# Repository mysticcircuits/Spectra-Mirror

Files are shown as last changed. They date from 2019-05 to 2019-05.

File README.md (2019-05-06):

# Spectra-Mirror

The Spectra Mirror is an analog downsampler with a bunch of bells and whistles not found in other downsamplers.
The module is currently discontinued but is now available in an open hardware licence for those who still want
to build one.  Most of the well known DIY synth retailers as of now still have a few boards in stock, so if you
would like to build one without going through the process of getting the boards made yourself go ahead and
check them out, currently thonk, modular addict and synthcube all have them in stock.

The entire build is through hole with easy to find parts, there is one optional SMD matched transistor pair for 
those wanting superior tracking of the internal VCO.  I would say that this project is not for a complete beginner 
but would be quite easy for anyone with a fair amount of DIY experience.  The calibration procedure requires at 
least a multimeter and benefits from the use of an oscilloscope, although again this is not crucial.  Please read 
the build documentation if you want a better idea of the level of difficulty for the build.

For any questions or comments please visit the MW thread here 
https://www.muffwiggler.com/forum/viewtopic.php?p=2418444#2418444

========= FOR THOSE ATTEMPTING THE MATCHED TRANSISTOR PAIR =========

The following parts will be needed.  I am specifically making you source them as a "barrier for entry" as doing 
this matched transistor pair is not for DIY beginners.  SMD soldering aptitude is required.

Transistor pair is by diodes incorporated part # ZXTC2045E6TA

You will also need a 22k resistor and a 22nF capacitor.

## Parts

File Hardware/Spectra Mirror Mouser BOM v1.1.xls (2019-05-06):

SPECTRA-MIRROR |  |  | WEBLINK TO NON MOUSER PARTS: | Qty. | Notes
 |  | alpha | http://smallbear-electronics.mybigcommerce.com/alpha-single-gang-9mm-right-angle-pc-mount/ | 7 | Order 100kB linear variant
 |  |  | https://modularaddict.com/parts/synth-diy-parts/9mm-potentiometers
 |  |  | https://www.thonk.co.uk/shop/alpha-9mm-pots/
 | R0904N – B 100K , L- 25 KQ | song huei | https://www.thonk.co.uk/shop/ttpots/ | 3 | Order 100kB linear variant
 |  |  | https://modularaddict.com/parts/synth-diy-parts/9mm-tall-trimmer-potentiometers
 | PJ301BM | Kobiconn | https://www.thonk.co.uk/shop/3-5mm-jacks/ | 12 | be sure to buy washers
 |  |  | https://modularaddict.com/parts/jacks/pj301bm-jacks |  | only available in bag of 50 from here
 |  |  | http://smallbear-electronics.mybigcommerce.com/knurled-silver-center-colors/ | 7 | these are the knobs I use, in violet color
 |  |  | http://smallbear-electronics.mybigcommerce.com/large-fluted-silver-center-dot-index-colors/ | 1 | same as above
Mouser # | Mfr. # | Manufacturer | Description – MOUSER PARTS: | Order Qty.
595-TL074CNE4 | TL074CNE4 | Texas Instruments | Operational Amplifiers - Op Amps Quad Low-Noise JFET-Input | 2
926-LF398N/NOPB | LF398N/NOPB | Texas Instruments | Sample & Hold Amplifiers MONOLITHIC SAMPLE & HOLD CIRCUIT | 1
926-LM13700N/NOPB | LM13700N/NOPB | Texas Instruments | Transconductance Amplifiers Dual OP Amp Transconductance | 1
810-FK28C0G1H220J | FK28C0G1H220J | TDK | Multilayer Ceramic Capacitors MLCC - Leaded 22pF 50V C0G 5% | 1
80-R82EC2100AA50J | R82EC2100AA50J | Kemet | Film Capacitors 100volts 0.01uF 5% | 2
71-CCF5010K0FKE36 | CCF5010K0FKE36 | Vishay | Metal Film Resistors - Through Hole 1/3watts 10Kohms 1% | 4
71-CCF0747K0JKE36 | CCF0747K0JKE36 | Vishay | Metal Film Resistors - Through Hole 1/4watt 47Kohms 5% Rated to 1/2watt | 1
71-CCF07220KGKE36 | CCF07220KGKE36 | Vishay | Metal Film Resistors - Through Hole 1/4watt 220Kohms 2% Rated to 1/2watt | 15
71-CCF50-100K | CCF50100KFKR36 | Vishay | Metal Film Resistors - Through Hole 1/3watts 100Kohms 1% | 17
71-CCF501K00FKE36 | CCF501K00FKE36 | Vishay | Metal Film Resistors - Through Hole 1/3watts 1Kohms 1% | 10
71-CCF0722K0GKE36 | CCF0722K0GKE36 | Vishay | Metal Film Resistors - Through Hole 1/4watt 22Kohms 2% Rated to 1/2watt | 4
571-1-2199298-2 | 1-2199298-2 | TE Connectivity | IC & Component Sockets 8P DIP SKT 300 CL LADDER | 6
571-1-2199298-3 | 1-2199298-3 | TE Connectivity | IC & Component Sockets 14P DIP SKT 300 CL LADDER | 2
571-1-2199298-4 | 1-2199298-4 | TE Connectivity | IC & Component Sockets 16P DIP SKT 300 CL LADDER | 1
623-2743002112LF | 2743002112 | Fair-Rite | Ferrite Beads 43 BEAD ON LEAD Z=133OHM @ 100MHz | 2
625-1N4001E-E3/73 | 1N4001E-E3/73 | Vishay | Rectifiers Vr/50V Io/1A | 2
140-REA100M1HBK0511P | REA100M1HBK-0511P | Lelon | Aluminum Electrolytic Capacitors - Leaded 50V 10uF 20% 5x11mm | 2
517-929974-01-13-RK | 929974-01-13-RK | 3M | Headers & Wire Housings 13 CON STR BRDMNT SKT | 2
660-MFS1/4LCT52R153J | MFS1/4LCT52R153J | KOA Speer | Metal Film Resistors - Through Hole 15K ohm 5% | 1
71-RN60D-F-5K | RN60D5001FB14 | Vishay | Metal Film Resistors - Through Hole 1/4watt 5Kohms 1% 100ppm | 1
652-3296W-1-104LF | 3296W-1-104LF | Bourns | Trimmer Resistors - Through Hole 3/8" 100Kohms Sealed Vertical Adjust | 1
652-3296W-1-503LF | 3296W-1-503LF | Bourns | Trimmer Resistors - Through Hole 3/8" 50Kohms Sealed Vertical Adjust | 1
652-3296W-1-102LF | 3296W-1-102LF | Bourns | Trimmer Resistors - Through Hole 3/8" 1Kohms Sealed Vertical Adjust | 1
595-TL071CP | TL071CP | Texas Instruments | Operational Amplifiers - Op Amps JFET Input Low Noise | 1
595-TL072IP | TL072IP | Texas Instruments | Operational Amplifiers - Op Amps Dual JFET In Low N | 3
696-SLX-LX3054ID | SLX-LX3054ID | Lumex | Standard LEDs - Through Hole 3mm LED Lamps | 2
512-2N3906TFR | 2N3906TFR | Fairchild Semiconductor | Bipolar Transistors - BJT PNP Transistor General Purpose | 1
512-2N3904BU | 2N3904BU | Fairchild Semiconductor | Bipolar Transistors - BJT NPN Transistor General Purpose | 1
603-MFR-25FRF521M | MFR-25FRF52-1M | Yageo | Metal Film Resistors - Through Hole 1M ohm 1/4W 1% | 1
647-QYX1H222KTP | QYX1H222KTP | Nichicon | Film Capacitors 50volts 0.0022uF | 1
855-M22-2020505 | M22-2020505 | Harwin | Headers & Wire Housings 5+5 DIL PIN HDR GOLD VERTICAL | 1
571-4-146262-1 | 4-146262-1 | TE Connectivity | Headers & Wire Housings 06 MODII HDR DRST B/A 100W/HD | 2
81-PV36W504C01B00 | PV36W504C01B00 | Bourns | Trimmer Resistors - Through Hole 500Kohms 10mm Square 25turn | 1
595-LT1013CP | LT1013CP | Texas Instruments | Precision Amplifiers Dual Precision | 1
594-K104K15X7RF5UH5 | K104K15X7RF5UH5 | Vishay | Multilayer Ceramic Capacitors MLCC - Leaded .1uF 50volts 10% 5.0mm X7R | 1

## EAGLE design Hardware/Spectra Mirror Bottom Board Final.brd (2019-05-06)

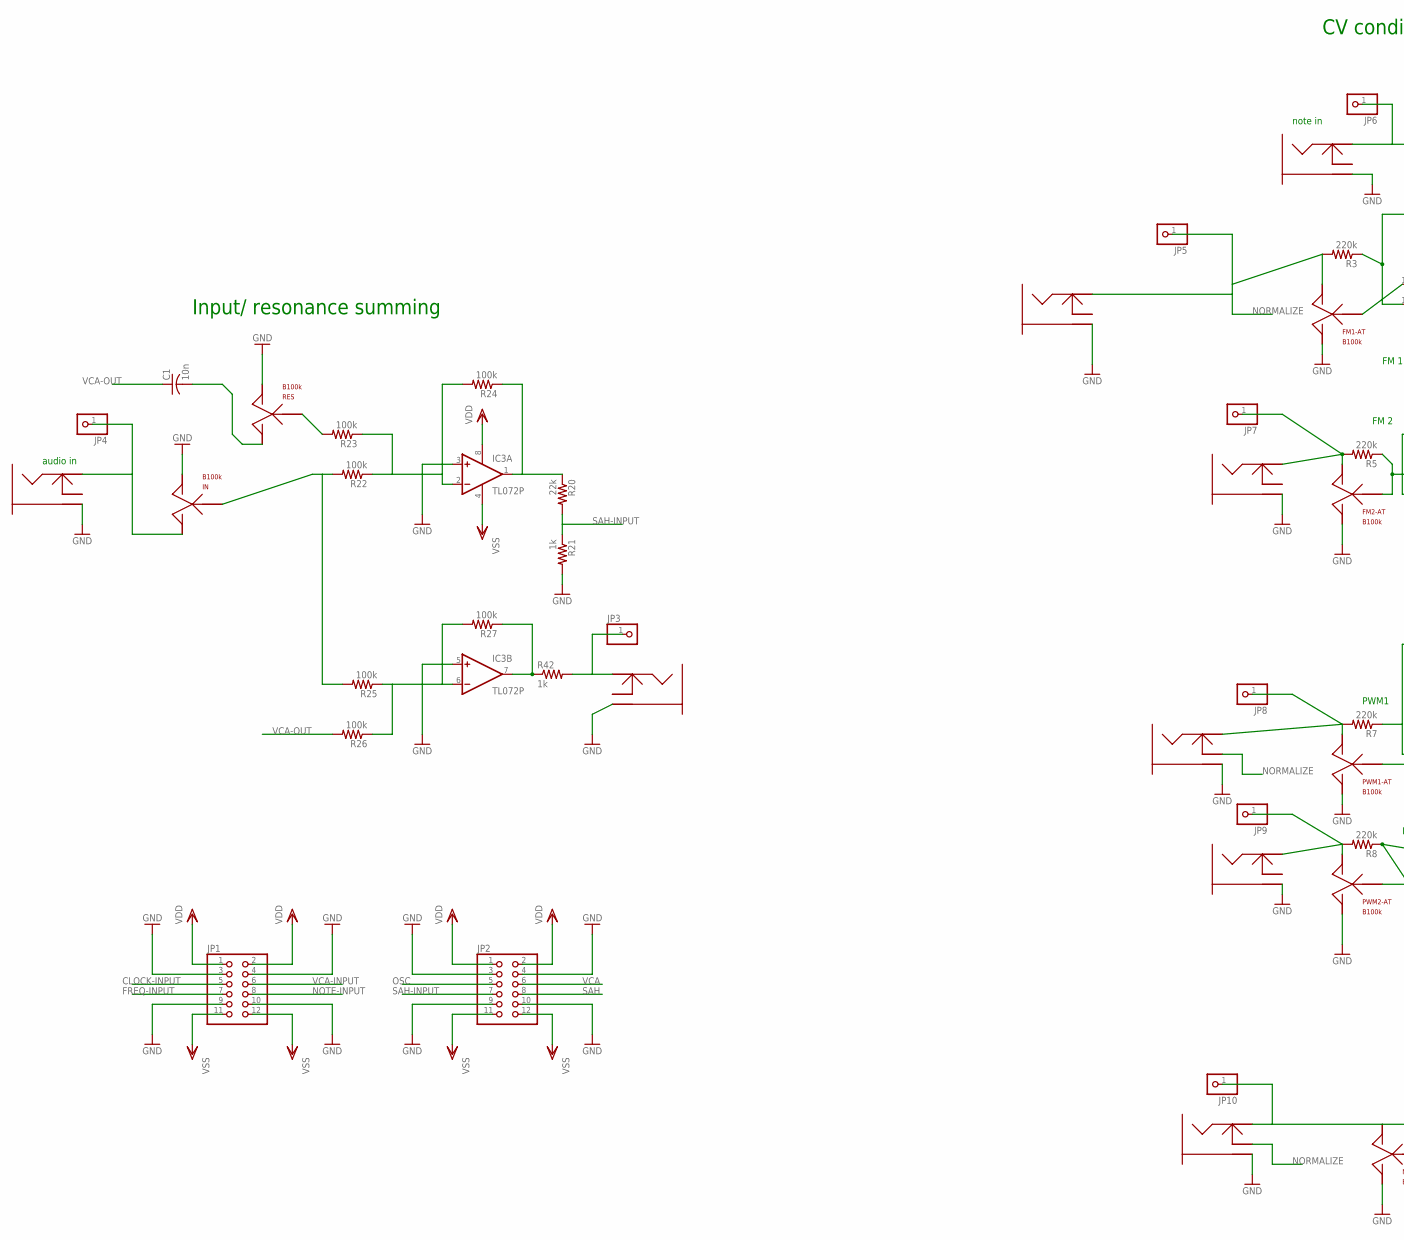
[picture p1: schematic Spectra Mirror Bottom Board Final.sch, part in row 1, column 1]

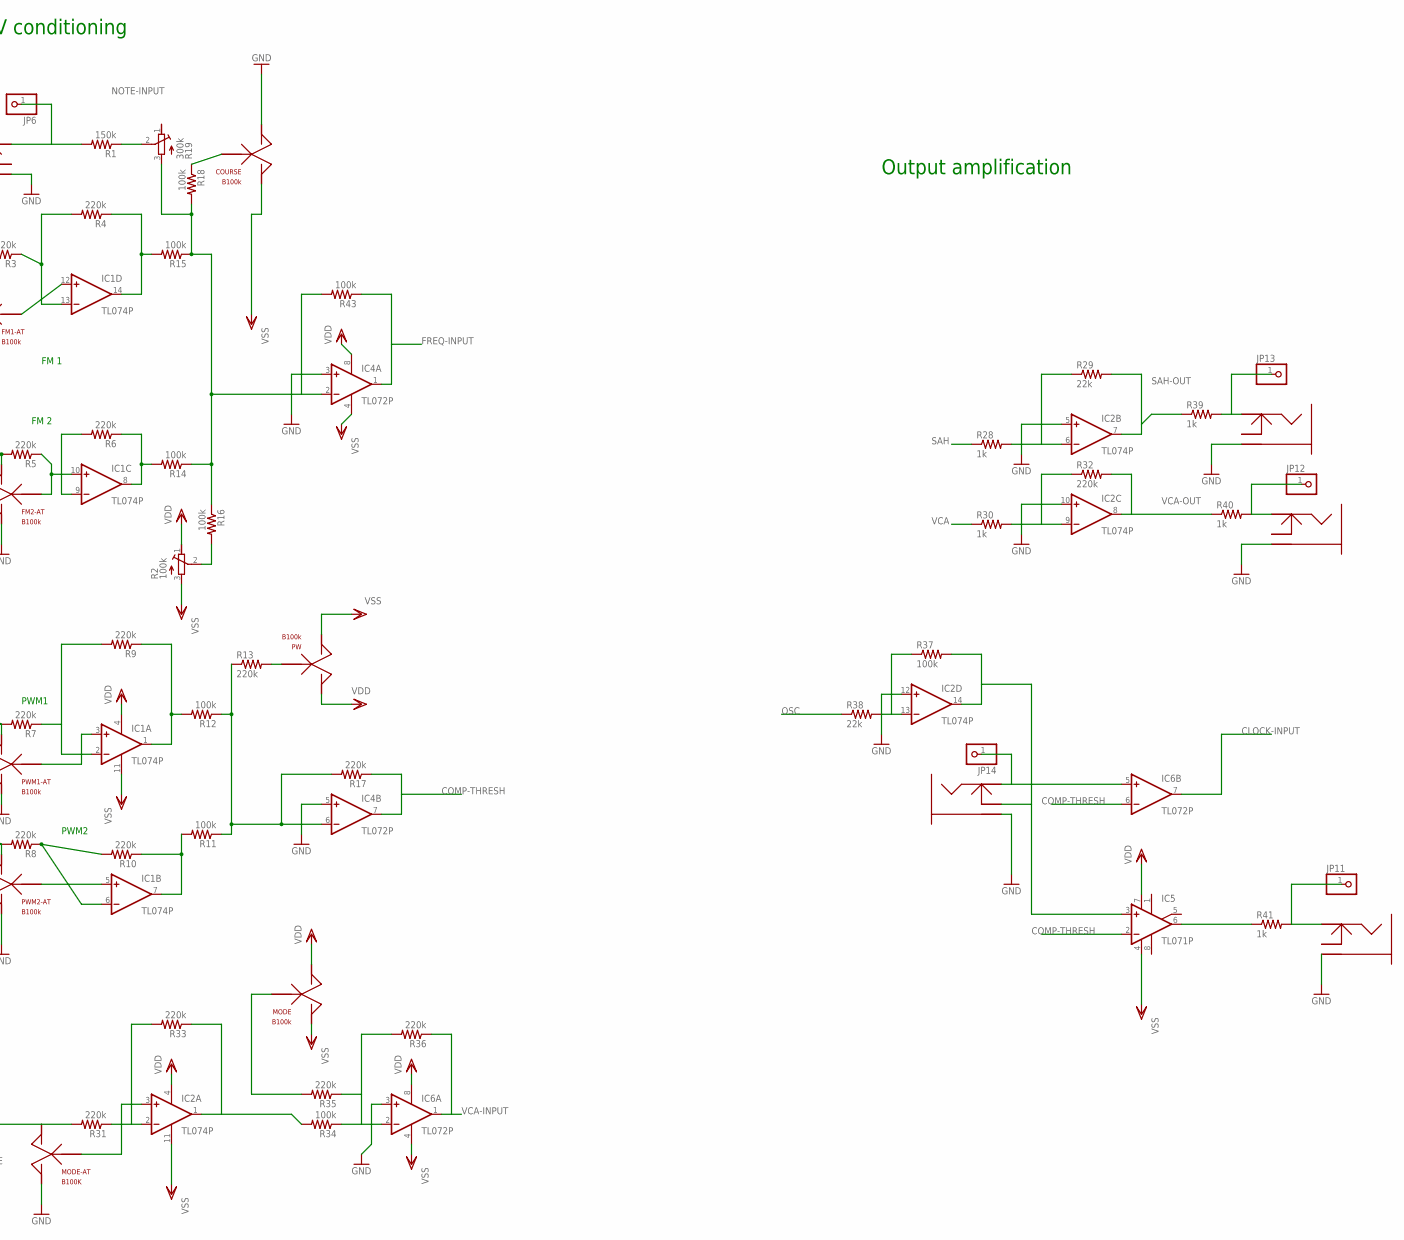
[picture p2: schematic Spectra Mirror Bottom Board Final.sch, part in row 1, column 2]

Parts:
C1: 10n; C050-025X075
COURSE: B100k; ALPHAPOT_BOARDMOUNT
FM1-AT, FM2-AT: B100k; ALPHAPOT_BOARDMOUNT
IC1, IC2: TL074P; DIL14
IC3, IC4, IC6: TL072P; DIL08
IC5: TL071P; DIL08
IN: B100k; ALPHAPOT_BOARDMOUNT
JP1, JP2: PINHD-2X6; 2X06
JP3, JP4, JP5, JP6, JP7, JP8, JP9, JP10, JP11, JP12, JP13, JP14: PINHD-1X1; 1X01
MODE: B100k; ALPHAPOT_BOARDMOUNT
MODE-AT: B100K; ALPHAPOT_BOARDMOUNT
PW: B100k; ALPHAPOT_BOARDMOUNT
PWM1-AT, PWM2-AT: B100k; ALPHAPOT_BOARDMOUNT
R1: 150k; 0204/7
R2: 100k; RTRIMT93YA
R3, R5, R7, R8, R10, R13, R17, R31, R32, R35, R36: 220k; 0204/7
R4, R6, R9, R33: 220k; 0204V
R11, R12, R14, R15, R16, R18, R22, R23, R24, R25, R26, R27, R34, R43: 100k; 0204/7
R19: 300k; RTRIMT93YA
R20, R38: 22k; 0204/7
R21, R28, R30, R39, R40, R41, R42: 1k; 0204/7
R29: 22k; 0204V
R37: 100k; 0204V
RES: B100k; ALPHAPOT_BOARDMOUNT
U$1, U$2, U$3, U$4, U$5, U$6, U$7, U$8, U$9, U$10, U$11, U$12: KOBICONPJ-301

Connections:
CLOCK-INPUT: IC6.7 (OUT), JP1.5
COMP-THRESH: IC4.7 (OUT), IC5.2 (-IN), IC6.6 (-IN), R17.1
FREQ-INPUT: IC4.1 (OUT), JP1.7, R43.1
GND: COURSE.LEFT, FM1-AT.RIGHT, FM2-AT.RIGHT, IC2.5 (+IN), IC2.10 (+IN), IC2.12 (+IN), IC3.3 (+IN), IC3.5 (+IN), IC4.3 (+IN), IC4.5 (+IN), IC6.3 (+IN), IN.RIGHT, JP1.3, JP1.4, JP1.9, JP1.10, JP2.3, JP2.4, JP2.9, JP2.10, MODE-AT.RIGHT, PWM1-AT.RIGHT, PWM2-AT.RIGHT, R21.2, RES.RIGHT, U$1.GND (GROUND), U$1.GND2 (GROUND), U$2.GND (GROUND), U$2.GND2 (GROUND), U$3.GND (GROUND), U$3.GND2 (GROUND), U$4.GND (GROUND), U$4.GND2 (GROUND), U$5.GND (GROUND), U$5.GND2 (GROUND), U$6.GND (GROUND), U$6.GND2 (GROUND), U$7.GND (GROUND), U$7.GND2 (GROUND), U$8.GND (GROUND), U$8.GND2 (GROUND), U$9.GND (GROUND), U$9.GND2 (GROUND), U$10.GND (GROUND), U$10.GND2 (GROUND), U$11.GND (GROUND), U$11.GND2 (GROUND), U$12.GND (GROUND), U$12.GND2 (GROUND)
KJDNFKDNF: IC1.13 (-IN), R3.1, R4.2
unnamed: R1.1, R19.2 (S)
unnamed: R2.2 (S), R16.2
unnamed: IC5.6 (OUT), R41.1
unnamed: IC1.14 (OUT), R4.1, R15.2
unnamed: FM1-AT.MID, IC1.12 (+IN)
unnamed: FM2-AT.MID, IC1.10 (+IN), R5.1
unnamed: IC1.9 (-IN), R6.2
unnamed: FM2-AT.LEFT, JP7.1, R5.2, U$4.IN (INPUT)
unnamed: IC1.8 (OUT), R6.1, R14.2
unnamed: JP9.1, PWM2-AT.LEFT, R8.2, U$11.IN (INPUT)
unnamed: IC1.6 (-IN), R8.1, R10.2
unnamed: JP8.1, PWM1-AT.LEFT, R7.2, U$12.IN (INPUT)
unnamed: IC1.2 (-IN), R7.1, R9.2
unnamed: IC1.1 (OUT), R9.1, R12.2
unnamed: IC1.3 (+IN), PWM1-AT.MID
unnamed: IC1.5 (+IN), PWM2-AT.MID
unnamed: IC1.7 (OUT), R10.1, R11.2
unnamed: IC4.6 (-IN), R11.1, R12.1, R13.1, R17.2
unnamed: PW.MID, R13.2
unnamed: IC4.2 (-IN), R14.1, R15.1, R16.1, R18.2, R19.3 (A), R43.2
unnamed: COURSE.MID, R18.1
unnamed: JP10.1, MODE-AT.LEFT, R31.2, U$10.IN (INPUT)
unnamed: IN.LEFT, JP4.1, U$1.IN (INPUT)
unnamed: IN.MID, R22.2, R25.2
unnamed: IC3.6 (-IN), R25.1, R26.1, R27.2
unnamed: IC3.1 (OUT), R20.1, R24.1
unnamed: IC2.2 (-IN), R31.1, R33.2
unnamed: IC3.2 (-IN), R22.1, R23.1, R24.2
unnamed: IC3.7 (OUT), R27.1, R42.1
unnamed: R23.2, RES.MID
unnamed: IC2.1 (OUT), R33.1, R34.2
unnamed: IC2.9 (-IN), R30.2, R32.1
unnamed: IC2.3 (+IN), MODE-AT.MID
unnamed: IC2.6 (-IN), R28.2, R29.1
unnamed: C1.2, RES.LEFT
unnamed: IC6.2 (-IN), R34.1, R35.1, R36.2
unnamed: IC2.13 (-IN), R37.1, R38.2
unnamed: IC2.14 (OUT), IC5.3 (+IN), R37.2, U$9.SWITCH
unnamed: MODE.MID, R35.2
unnamed: IC6.5 (+IN), JP14.1, U$9.IN (INPUT)
unnamed: JP11.1, R41.2, U$5.IN (INPUT)
unnamed: JP12.1, R40.2, U$7.IN (INPUT)
unnamed: JP13.1, R39.2, U$6.IN (INPUT)
unnamed: JP3.1, R42.2, U$8.IN (INPUT)
NORMALIZE: FM1-AT.LEFT, JP5.1, R3.2, U$3.IN (INPUT), U$10.SWITCH, U$12.SWITCH
NOTE-INPUT: JP1.8, JP6.1, R1.2, U$2.IN (INPUT)
OSC: JP2.5, R38.1
SAH: JP2.8, R28.1
SAH-INPUT: JP2.7, R20.2, R21.1
SAH-OUT: IC2.7 (OUT), R29.2, R39.1
VCA: JP2.6, R30.1
VCA-INPUT: IC6.1 (OUT), JP1.6, R36.1
VCA-OUT: C1.1, IC2.8 (OUT), R26.2, R32.2, R40.1
VDD: IC1.4 (V+), IC2.4 (V+), IC3.8 (V+), IC4.8 (V+), IC5.7 (V+), IC6.8 (V+), JP1.1, JP1.2, JP2.1, JP2.2, MODE.LEFT, PW.LEFT, R2.1 (E)
VSS: COURSE.RIGHT, IC1.11 (V-), IC2.11 (V-), IC3.4 (V-), IC4.4 (V-), IC5.4 (V-), IC6.4 (V-), JP1.11, JP1.12, JP2.11, JP2.12, MODE.RIGHT, PW.RIGHT, R2.3 (A)

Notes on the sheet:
note in
FM 1
FM 2
audio in
PWM1
PWM2
Input/ resonance summing
CV conditioning
Output amplification

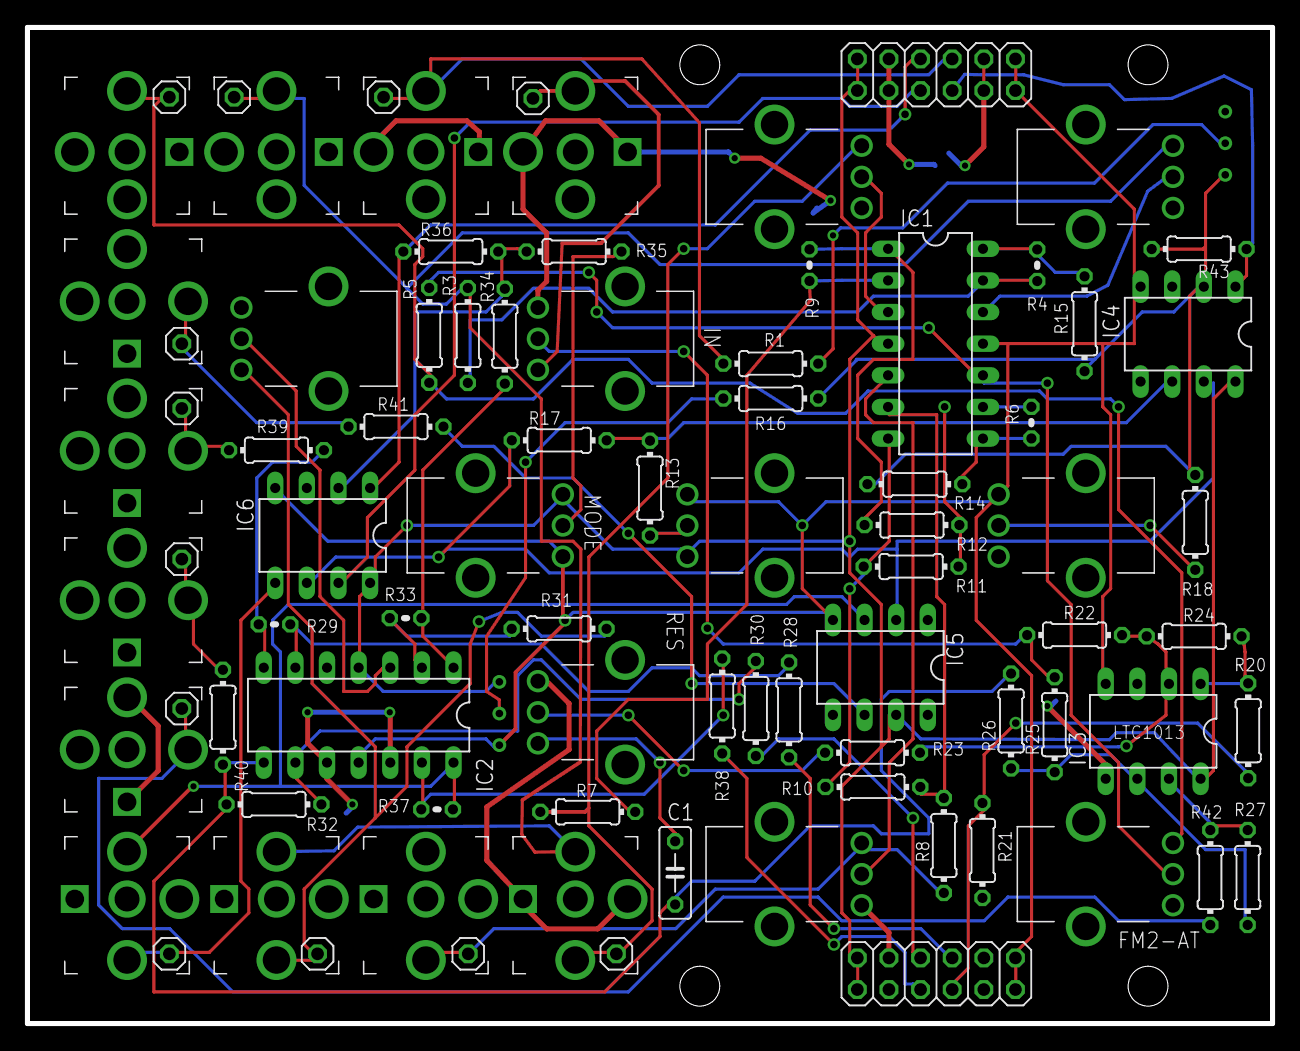
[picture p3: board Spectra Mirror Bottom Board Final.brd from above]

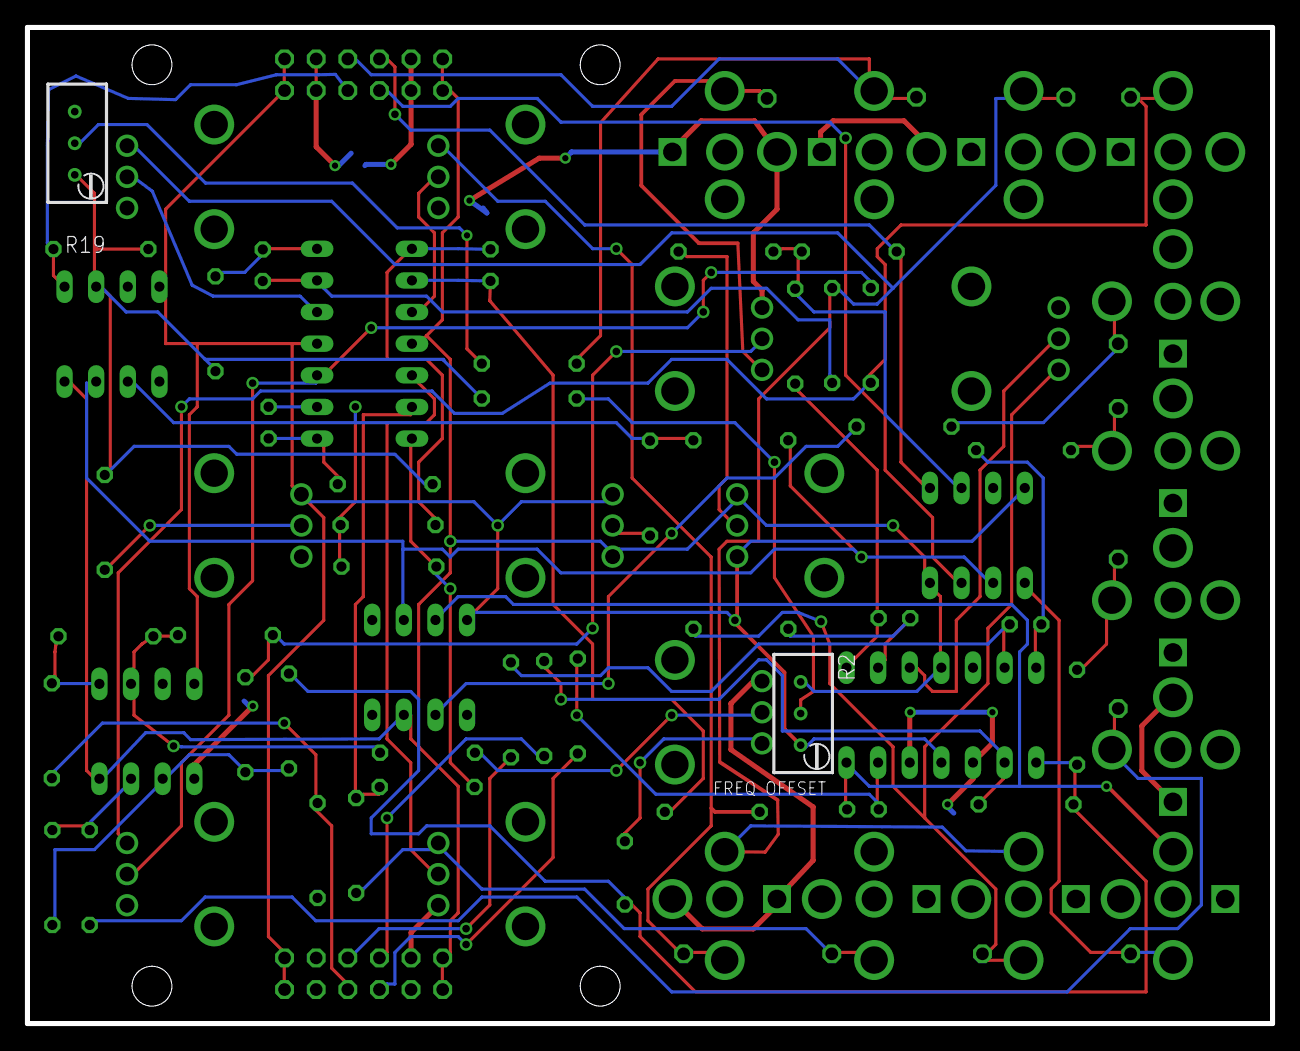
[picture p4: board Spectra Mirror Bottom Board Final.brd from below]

Board: 2 copper layers, 100.0 x 80.0 mm, 86 parts (2 on the bottom side), 60 nets.

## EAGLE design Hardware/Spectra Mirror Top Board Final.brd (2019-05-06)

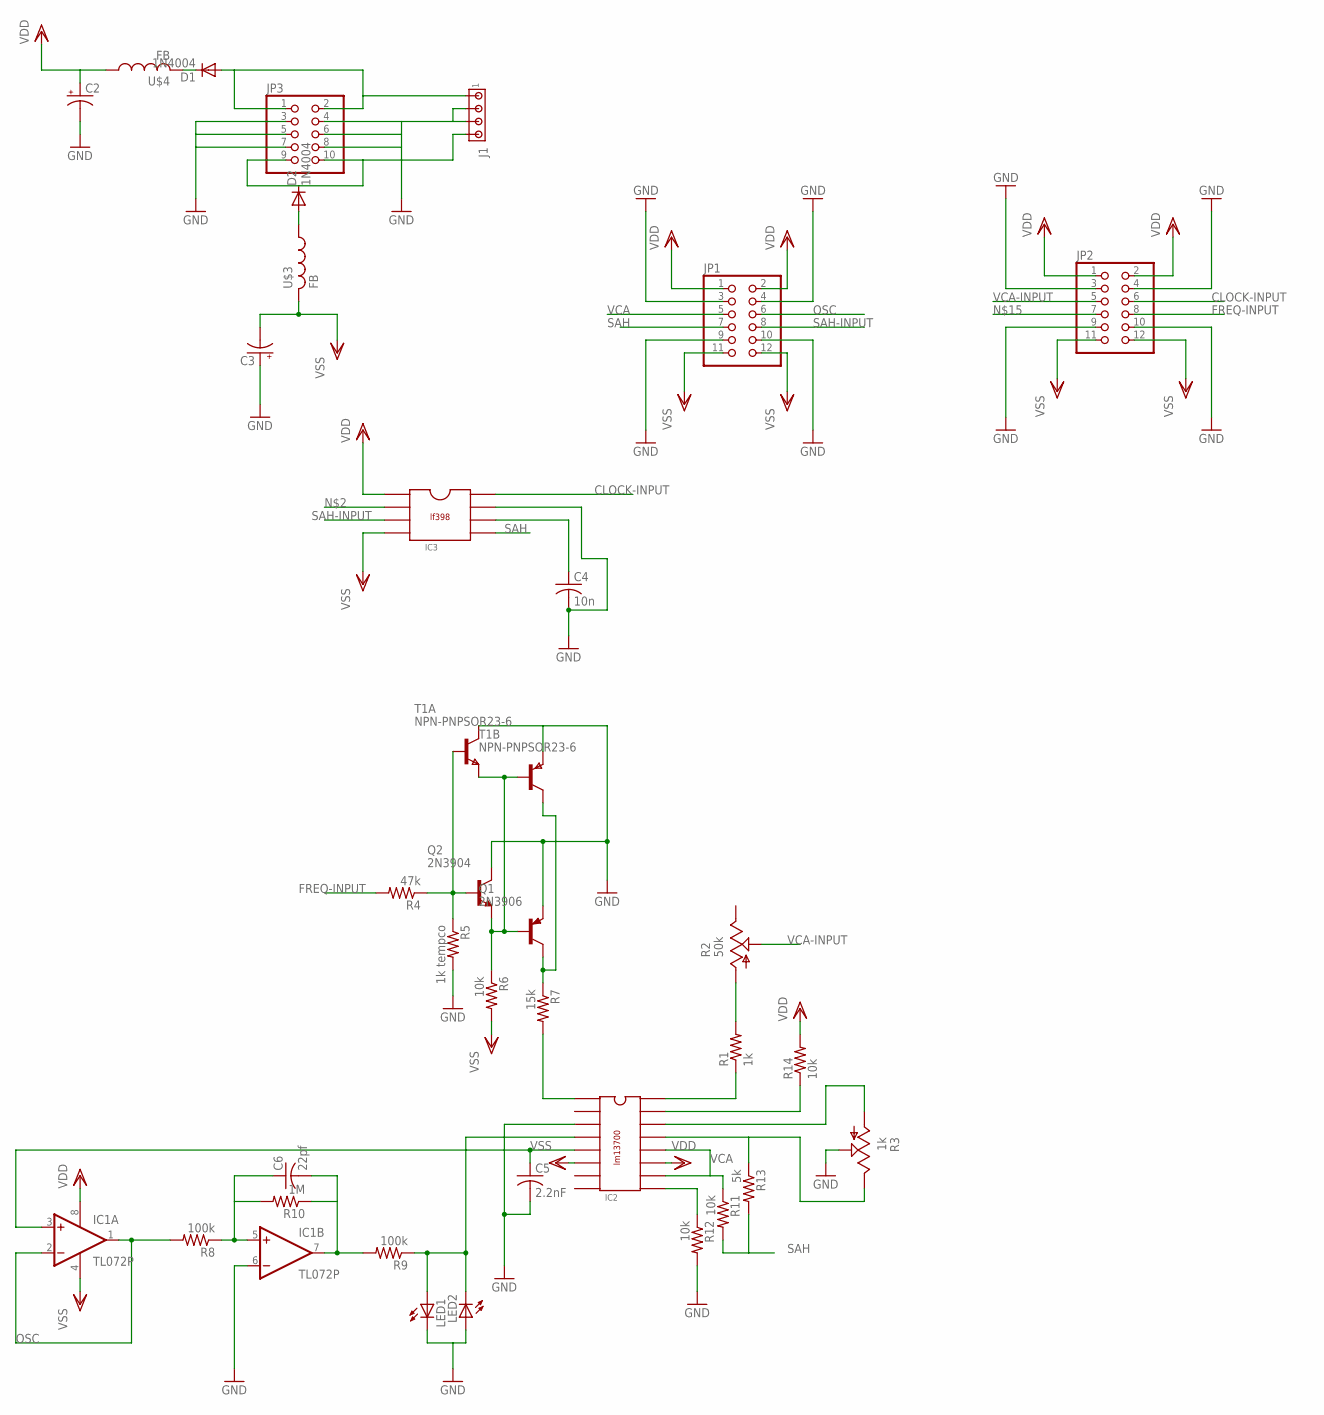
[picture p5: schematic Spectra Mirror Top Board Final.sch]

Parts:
C2, C3: CPOL-USE2.5-5; E2,5-5
C4: 10n; C050-024X044
C5: 2.2nF; C050-024X044
C6: 22pf; C050-024X044
D1, D2: 1N4004; DO41-10
IC1: TL072P; DIL08
IC2: LM13700; DIL16
IC3: LF398; DIL08
J1: MTA04-156; 1X4MTA
JP1, JP2: PINHD-2X6; 2X06
JP3: PINHD-2X5; 2X05
LED1, LED2: LED3MM
Q1: 2N3906; TO92
Q2: 2N3904; TO92
R1: 1k; 0204/7
R2: 50k; B64Y
R3: 1k; B64Y
R4: 47k; 0204/7
R5: 1k tempco; 0204/7
R6, R11, R12, R14: 10k; 0204/7
R7: 15k; 0204/7
R8, R9: 100k; 0204/7
R10: 1M; 0204/7
R13: 5k; 0204/7
T1: NPN-PNPSOR23-6; SOT23-6
U$3, U$4: FB

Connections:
CLOCK-INPUT: IC3.8, JP2.6
FREQ-INPUT: JP2.8, R4.2
GND: C2.-, C3.+, C4.2, C5.2, IC1.6 (-IN), IC2.3, IC3.7, J1.2, J1.3, JP1.3, JP1.4, JP1.9, JP1.10, JP2.3, JP2.4, JP2.9, JP2.10, JP3.3, JP3.4, JP3.5, JP3.6, JP3.7, JP3.8, LED1.K (C), LED2.A, Q1.3 (E), Q2.1 (C), R3.S, R5.2, R12.2, T1.1 (C), T1.4 (E)
unnamed: D1.A, J1.1, JP3.1, JP3.2
unnamed: Q1.2 (B), Q2.3 (E), R6.1, T1.5 (B), T1.6 (E)
unnamed: Q2.2 (B), R4.1, R5.1, T1.2 (B)
unnamed: C4.1, IC3.6
unnamed: C6.1, IC1.5 (+IN), R8.1, R10.2
unnamed: Q1.1 (C), R7.1, T1.3 (C)
unnamed: IC2.1, R7.2
unnamed: IC2.4, LED1.A, LED2.K (C), R9.1
unnamed: C6.2, IC1.7 (OUT), R9.2, R10.1
unnamed: D2.C, J1.4, JP3.9, JP3.10
unnamed: C5.1, IC1.3 (+IN), IC2.5
unnamed: IC2.9, R12.1
unnamed: IC2.13, R3.E, R13.1
unnamed: IC2.14, R3.A
unnamed: IC2.15, R14.1
unnamed: IC2.16, R1.1
unnamed: R1.2, R2.A
unnamed: D1.C, U$4.P$2 (2)
unnamed: D2.A, U$3.P$1 (1)
OSC: IC1.1 (OUT), IC1.2 (-IN), JP1.6, R8.2
SAH: IC3.5, JP1.7, R11.2, R13.2
SAH-INPUT: IC3.3, JP1.8
VCA: IC2.10, IC2.12, JP1.5, R11.1
VCA-INPUT: JP2.5, R2.S
VDD: C2.+, IC1.8 (V+), IC2.11, IC3.1, JP1.1, JP1.2, JP2.1, JP2.2, R14.2, U$4.P$1 (1)
VSS: C3.-, IC1.4 (V-), IC2.6, IC3.4, JP1.11, JP1.12, JP2.11, JP2.12, R6.2, U$3.P$2 (2)

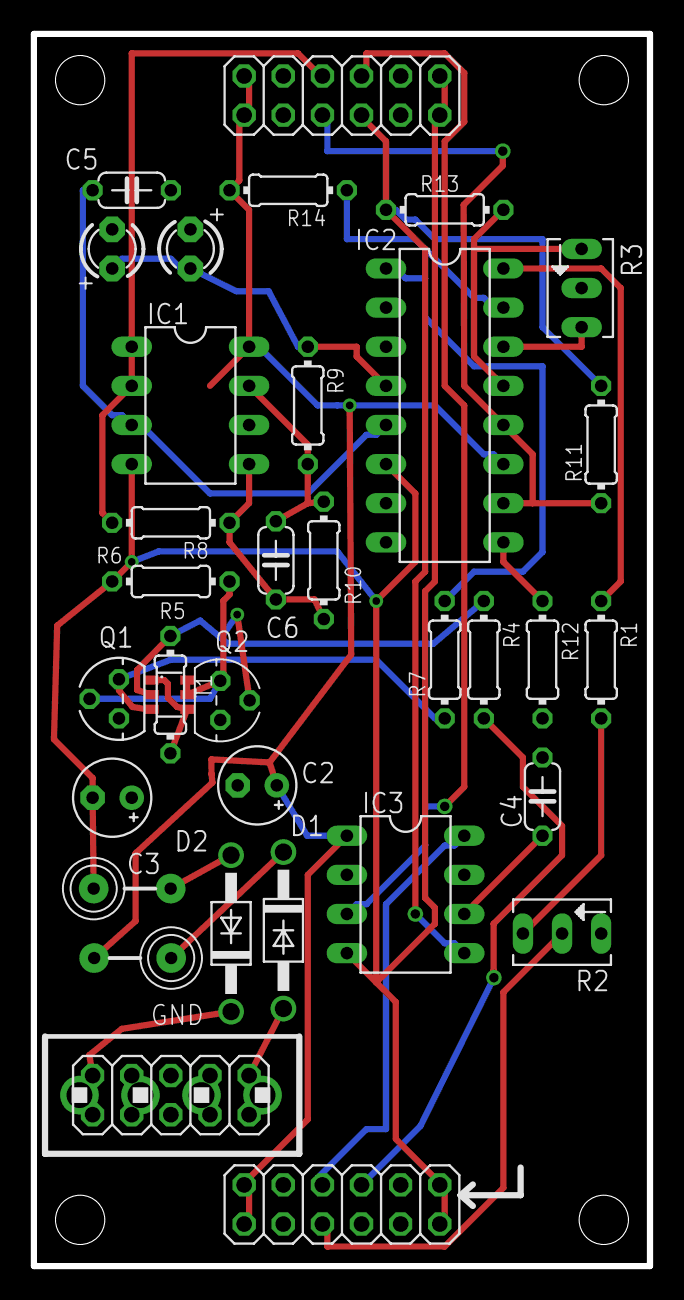
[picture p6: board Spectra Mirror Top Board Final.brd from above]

Board: 2 copper layers, 40.0 x 80.0 mm, 35 parts (0 on the bottom side), 29 nets.

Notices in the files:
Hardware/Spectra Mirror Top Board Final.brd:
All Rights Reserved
